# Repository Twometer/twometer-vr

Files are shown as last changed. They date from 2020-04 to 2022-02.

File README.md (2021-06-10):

<p align="center">
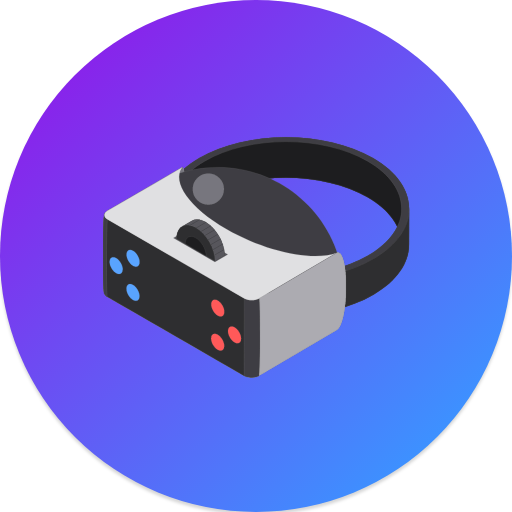
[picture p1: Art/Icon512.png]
  
  <h1 align="center">Twometer VR</h1>
</p>

An open-source alternative to commercial hand trackers such as Oculus Touch or PS Move, because Virtual Reality should not be expensive.

## Getting started

To get started with TwometerVR, check out the [homepage](https://twometer.dev/vr/).

On this page, you can find details about the project, all the technical details, as well as the download links for the hardware PCB/CAD files.

## Repository layout
- Art: All the icons, designs etc.
- Docs: MkDocs source files
- TVR.Service: The core application which manages the controllers and their inputs
- TVR.Driver: An OpenVR driver that can receive the data from the service
- TVR.Firmware: The firmware that runs on the controllers
- TVR.Setup: Setup files for building new releases

>  Looking for the code of version 1? See [here](https://github.com/Twometer/twometer-vr/tree/1.x).

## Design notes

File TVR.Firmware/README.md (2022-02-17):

# Firmware

Source code for the firmware running on the TwometerVR controllers, designed for ESP8266 chips.

## Building

You need:

-   PlatformIO (VS Code extension)
-   An ESP8266 programming device

## Recommended upload settings

-   CPU Speed: 160 MHz
-   Espressif Version: 2.2.1+100

> These are set automatically by the PlatformIO config

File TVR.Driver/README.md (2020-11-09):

# Driver
OpenVR driver implementation which connects the TVR service to games

### Directory

- `lib/`: OpenVR SDK
- `ovr/`: OpenVR driver manifests
- `src/`: Source files

### Installing
The release installation package will automatically install the driver for you. If you want to do it yourself, see the next section.

### Building from source
You will need:

- CLion or other CMake compatible IDE
- The submodules for this repo to get `.\lib\openvr`
- The MSVC compiler and Windows

Building:

- Run a CMake release build. It should automatically create the `driver_vr.dll` file required by SteamVR.
- Copy the dll file to `.\ovr\tvr\bin\win64\driver_tvr.dll`.

Installing: Run `.\ovr\Install.ps1`

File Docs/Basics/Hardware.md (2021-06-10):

# Hardware files
Here you can find the source files for building the hardware (PCBs and 3D models)

### PCBs

Each controller has three PCBs in it. They are all on EasyEDA and can be downloaded here:

- [Mainboard](https://oshwlab.com/Twometer/twometer-vr-2-0)
- [Buttons PCB](https://oshwlab.com/Twometer/twometer-vr-2-0-buttons)
- [LED PCB](https://oshwlab.com/Twometer/twometer-vr-2-0-led)

### CAD files

The case for a controller also consists of multiple 3D-printed parts. The Fusion360 files can be downloaded here:

- [Controller case](https://a360.co/38ymnGe)
- [Tracker ball](https://a360.co/38zLkB1)
- [Tracker ball adapter](https://a360.co/3poNDxz)
- [Buttons](https://a360.co/3ppm47l)

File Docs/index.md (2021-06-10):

# Welcome

TwometerVR is an open-source alternative to commercial VR hand/body tracking systems.

It's primarily intended for those who have VR headsets such as the Oculus DK2 that don't include controllers. It is a low-cost alternative to expensive commercial devices such as the PS Move or Oculus Touch system.

## Features

- 3D hand tracking controllers with 7 buttons and 9-DoF IMUs
- Works with BeatSaber, VRChat, or any other SteamVR game
- Low-cost with around $15 per controller
- Fully open-source and open-hardware

Although there is currently no implementation of full-body-tracking, the system is technically fully capable of supporting it.

## Getting started

As this is currently a hobby project of mine, there are no ready-made products or kits available for purchase.

To learn about the way the system works, check out the [system structure page](/Basics/System structure). If you're interested in the hardware, you can find all the required 3D models and PCB layouts on the [hardware page](Hardware/). The source code is available in the [GitHub repo](https://github.com/Twometer/twometer-vr).

## Pictures

todo

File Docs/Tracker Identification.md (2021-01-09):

# Tracker identification

When registering with the server, the tracker transmits its class, color and serial number. The server then generates a unique 8-bit ID for that tracker. For subsequent pose updates, only this ID is sent.

### Tracker colors

Trackers are identified by the color of their tracking ball. The following colors are reserved as they were determined to be the most distinguishable by the video camera. May change in the future as tests go on.

- `0x00`: Invalid (internal use)
- `0x01`: Red (#FF0000): Left hand
- `0x02`: Blue (#0000FF): Right hand
- `0x03`: Green (#00FF00): Left leg
- `0x04`: Magenta (#FF00FF): Right leg
- `0x05`: Cyan (#FFFF00): Hips
- `0x06`: Yellow (#FFFF00): Generic
  - Not required for 5-point body tracking and may therefore be used for any other object that should be tracked.
- `..0x7F`: Reserved for future use
- `0x80..0xFF`: May be used by extensions

### Tracker classes

- `0x00`: Invalid (internal use)
- `0x01`: Controller
- `0x02`: Body tracker
- `0x03`: Generic tracker
- `..0x7F`: Reserved for future use
- `0x80..0xFF`: May be used by extensions

### Tracker IDs

Tracker IDs are a random ID that is used to identify all trackers after `0x82 Handshake`. 

To ensure uniqueness in the current tracking setup, IDs are managed by the server. The server informs the client of its ID using the `0x83 Handshake Reply` packet.

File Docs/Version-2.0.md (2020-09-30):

# Twometer VR 2.0
Roadmap and design concept for the next generation of Twometer VR

## Roadmap

- New IMU chip for a drift-free VR experience
- More buttons on the controller to support more games
- Faster and more stable networking protocol
- Flexible, extensible, yet simple design
- Support multiple cameras and arbitrary angles
- Support 5P full-body tracking

## Naming

- Tracker: Any tracked device.
- Controller: Handheld tracked devices with button input capabilities.
- Server: The main server running in the TwometerVR service. May also be called 'service'.
- Driver: The 'driver' extension for SteamVR.

## Tracker identification

When registering with the server, the tracker transmits its class, color and model number. The server then generates a unique 8-bit ID for that tracker. For subsequent pose updates, only this ID is sent.

### Tracker colors

Trackers are identified by the color of their tracking ball. The following colors are reserved as they were determined to be the most distinguishable by the video camera. May change in the future as tests go on.

- `0x00`: Invalid (internal use)
- `0x01`: Red (#FF0000): Left hand
- `0x02`: Blue (#0000FF): Right hand
- `0x03`: Green (#00FF00): Left leg
- `0x04`: Magenta (#FF00FF): Right leg
- `0x05`: Cyan (#FFFF00): Hips
- `0x06`: Yellow (#FFFF00): Generic
  - Not required for 5-point body tracking and may therefore be used for any other object that should be tracked.
- `..0x7F`: Reserved for future use
- `0x80..0xFF`: May be used by extensions

### Tracker classes

- `0x00`: Invalid (internal use)
- `0x01`: Controller
- `0x02`: Body tracker
- `0x03`: Generic tracker
- `..0x7F`: Reserved for future use
- `0x80..0xFF`: May be used by extensions

### Tracker IDs

Tracker IDs are a random ID that is used to identify all trackers after the `0x82 Server Hello`. 

To ensure uniqueness in the current tracking setup, IDs are managed by the server. The server informs the client of its ID using the `0x83 Client Hello` packet.

## Next-gen positional tracking

The next generation positional tracking should allow for arbitrary camera angles, and multiple cameras for a larger tracking space and more accuracy.

#### Definitions

- Image space: Raw camera image space, consisting of a 2D image position and a radius
- Camera space: Ball position in 3D space, unprojected using camera parameters, but has its origin at the camera.
- World space: Ball position in 3D space, transformed so that the origin is at the center of the playspace.

#### Basic algorithm (idea)

1. Isolate the tracker ball from the image and determine position and radius
2. Using the previously determined camera parameters, unproject the tracker ball into camera space.
3. By comparing the nominal playspace cube with the rotated playspace cube registered during a calibration step, compute a matrix from camera space into world space.
4. Use said matrix to convert all camera space ball locations into world space ball locations.

## Steam VR

- Universe ID: `0x02 0x16 0x39 0xA0` = `2688095746`

## Protocol definitions

- All multi-byte integer values are little-endian
- Packets longer than 4 KB (4096 bytes) are not accepted by any endpoint
- `vec3`: 3 sequential 32-bit floating-point values in order `[x, y, z]` that encode a 3D-position
- `quat`: 4 sequential 32-bit floating-point values in order `[x, y, z, w]` that encode a quaternion
- `type[]`: Array of objects, is prefixed by a `[uint8 length]` that contains the number of objects in the array.
- `string`: NUL-terminated ASCII-encoded string

## Networking ports

- Server ⇄ Driver: `20156`
- Server ⇄ Tracker (Broadcast): `20157`
- Server ⇄ Tracker (Unicast): `20158`

## Driver Protocol

This UDP binary protocol is used for IPC between the server and the SteamVR driver.

### Base structure
```
[uint8 id][payload]
```

### 0x00 Tracker Connect

```
[uint8 trackerId][uint8 trackerClass][string modelNo]
```

### 0x01 Tracker Disconnect

If a tracker stops sending status updates for longer than 30 seconds, it is considered offline and the server will inform the driver of a lost tracker using this message.

```
[uint8 trackerId]
```

### 0x02 Tracker States

Used to tell the driver about state updates

```
[TrackerStates[] states]
```

#### Tracker state

```
[uint8 trackerId][uint16 buttons][vec3 position][quat rotation]
```

### `..0x7F` Reserved

This range is reserved for future use. Extensions may use the `0x80..0xFF` packet range.

## Tracker Protocol

Also an UDP-based binary protocol; used to tell the server about the tracker state.

### Base structure
```
[uint8 id][payload]
```

I the MSB of `id` is set (`id > 0x7F`), then the lower 7 bytes of ID are treated as the ID of a management packet. If it's not  set, the packet is interpreted as a tracker state packet and the lower 7 bytes are the tracker ID.

### `0x00-0x7F` Tracker State
```
[uint8 trackerId][uint16 buttons][quat rotation]
```

`buttons` is a bitmask for pressed buttons: LSB->MSB is button 0->15

#### Button IDs

- `0`: A
- `1`: B
- `2`: Up
- `3`: Down
- `4`: Left
- `5`: Right
- `6`: Trigger
- `7`: Menu
- `8..15`: reserved

### `0x80` Discovery (Use Broadcast Channel)

```
0x80   0x02 0x16 0x39 0xA0
pID    Identifier
```

Identifier is a static key that identifies the Twometer VR 2.0 universe. It's the same as the SteamVR universe ID.

The server must respond with `0x81 Discovery Reply`

### `0x81` Discovery Reply

```
0x81   [string serverIp]
```
 `serverIp` contains the IP or hostname of the server.

### `0x82` Server Hello

```
0x82   [uint8 trackerClass][uint8 colorId][string modelNo]
```

`modelNo` can be the ESP chip's model number.

The server must respond with `0x83 Client Hello`

### `0x83` Client Hello

```
0x83   [uint8 trackerId]
```

### `0x84` Haptic Feedback (To client only)

```
0x84   [uint16 durationMs]
```

### `..0xBF` Reserved

This packet range is reserved for (future) internal use.

Modified trackers may use the subsequent packet ID range `0xC0..0xFF` for extended functionality.

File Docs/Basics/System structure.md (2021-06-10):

# System structure

TwometerVR is a complex system with many components that need to work together in order to make it work. The components described in this document are named after the naming scheme [described here](/Meta/Naming). You may want to read this first for a clearer understanding.

## Trackers

Each tracker at least requires a glowing colored 4cm sphere for positional tracking. Trackers that also report orientation, as well as hand controllers, need more intelligent logic. They are based around an ESP8266 WiFi chip. Communication with the host computer is done using WiFi and a binary UDP protocol, which is documented [here](/Network/Driver%20Protocol). 

The WiFi chip streams the orientation of the controller along with the state of any buttons to the server. It can also receive messages, so that in the future one can add communication from the server to the client. This can be useful for features like haptic feedback.

To learn more about how the server knows which trackers are which, check out the [Tracker identification page](/Basics/Tracker identification).

## Server

The server is a program running on the host computer. It has multiple different functions:

It uses the computer's webcam (preferrably a PSMove camera for high refresh rates) to track the trackers' glowing spheres. Their 3D position is then computed and stored. The server also provides the UDP endpoint to which the trackers send their orientation and button data.

The server then merges all this data and transmits it to the SteamVR driver, which is required in order to play VR games and apps with the system.

## Driver

In order to let games know about the state of the trackers, TVR implements a SteamVR extension, called a driver. This  is the last step for the tracker data, which is received from the server and converted into a format SteamVR understands.

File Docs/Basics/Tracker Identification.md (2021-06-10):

# Tracker identification

When registering with the server, the tracker transmits its class, color and serial number. The server then generates a unique 7-bit ID for that tracker. For subsequent pose updates, only this ID is sent.

### Tracker colors

Trackers are identified by the color of their tracking ball. The following colors are reserved as they were determined to be the most distinguishable by the video camera. May change in the future as tests go on.

- `0x00`: Invalid (internal use)
- `0x01`: Red (#FF0000): Left hand
- `0x02`: Blue (#0000FF): Right hand
- `0x03`: Green (#00FF00): Left leg
- `0x04`: Magenta (#FF00FF): Right leg
- `0x05`: Cyan (#FFFF00): Hips
- `0x06`: Yellow (#FFFF00): Generic
  - Not required for 5-point body tracking and may therefore be used for any other object that should be tracked.
- `..0x7F`: Reserved for future use
- `0x80..0xFF`: May be used by extensions

### Tracker classes

- `0x00`: Invalid (internal use)
- `0x01`: Controller
- `0x02`: Body tracker
- `0x03`: Generic tracker
- `..0x7F`: Reserved for future use
- `0x80..0xFF`: May be used by extensions

### Tracker IDs

Tracker IDs are randomly generated numbers that are used to easily identify trackers after a `0x82 Handshake` packet. 

To ensure uniqueness in the current tracking setup, IDs are managed by the server. The server informs the client of its ID using the `0x83 Handshake Reply` packet.

More information about these packets packet can be found in the [protocol documentation](/Network/Tracker protocol).

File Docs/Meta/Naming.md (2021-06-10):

# Naming

Throughout the TwometerVR documentation, various naming conventions and abbreviations are used:

## Names

- Tracker: Any tracked device.
- Controller: Handheld tracked devices with button input capabilities.
- Server: The main server running in the TwometerVR service. May also be called 'service'.
- Driver: The 'driver' extension for SteamVR.
- Host computer: The PC that runs the server, SteamVR etc.

## Abbreviations

- TVR: TwometerVR 
- OVR: OpenVR / SteamVR

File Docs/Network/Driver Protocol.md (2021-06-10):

# Driver Protocol

This UDP binary protocol is used for IPC between the server and the SteamVR driver.

### Base structure

```
[uint8 id][payload]
```

### `0x00` Tracker Connect

Sent by the server to inform the driver of a new tracker

```
[uint8 trackerId][uint8 trackerClass][uint8 trackerColor][string serialNo]
```

### `0x01` Tracker Disconnect

If a tracker stops sending status updates for longer than 30 seconds, it is considered offline and the server will inform the driver of a lost tracker using this message.

```
[uint8 trackerId]
```

### `0x02` Tracker States

Used to tell the driver about state updates

```
[TrackerStates[] states]
```

#### Tracker state

```
[uint8 trackerId][uint16 buttons][vec3 position][vec4 rotation][bool inRange]
```

### `0x03` Request Info

Sent by the driver on starting up to request tracker information.

Has no content.

### `..0x7F` Reserved

This range is reserved for future use. Extensions may use the `0x80..0xFF` packet range.

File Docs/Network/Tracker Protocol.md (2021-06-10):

# Tracker Protocol

This UDP binary protocol is used for communication between the server and the trackers.

### Base structure

```
[uint8 id][payload]
```

If the MSB of `id` is set (`id & 0x80 != 0`), then the lower 7 bytes of ID are treated as the ID of a management packet. If it's not  set, the packet is interpreted as a tracker state packet and the lower 7 bytes are the tracker ID.

### `0x00-0x7F` Tracker State

```
[uint8 trackerId][uint16 buttons][vec4 rotation]
```

`buttons` is a bitmask for pressed buttons: LSB->MSB is button 0->15

The button IDs are defined in the definitions file.

### `0x80` Discovery (Use Broadcast Channel)

```
0x80   0x02 0x16 0x39 0xA0
pID    Identifier
```

Identifier is a static key that identifies the Twometer VR 2.0 universe. It's the same as the SteamVR universe ID.

The server must respond with `0x81 Discovery Reply`

### `0x81` Discovery Reply

```
0x81   [string serverIp]
```

 `serverIp` contains the IP or hostname of the server.

### `0x82` Handshake

```
0x82   [uint8 trackerClass][uint8 colorId][string serialNo]
```

`serialNo` is formatted as `[manufacturerId][chipId]`, so for TwometerVR controllers with an ESP Chip `TVR[ESP.chipId]`.

The server must respond with `0x83 Handshake Reply`

### `0x83` Handshake Reply

```
0x83   [uint8 trackerId]
```

### `..0xBF` Reserved

This packet range is reserved for (future) internal use.

Modified trackers may use the subsequent packet ID range `0xC0..0xFF` for extended functionality.

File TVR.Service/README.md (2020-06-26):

# Service
The Service is the core of TwometerVR. It is the bridge between all the connected devices and SteamVR, provides a user interface and handles visual controller tracking using the webcam.

## Project structure
- Core libraries
  - `TVR.Service.Core`: Contains all the tracking and processing logic
  - `TVR.Service.Network`: Implements the servers, discovery and protocols
  - `TVR.Service.Common`: Common API which makes it easier to build a frontend
- Frontends
  - `TVR.Service.CLI`: Console interface for debugging.
  - `TVR.Service.UI`: User-friendly modern GUI frontend. Includes setup assistant.

## Getting Started
For details on how to configure and run the service, check out the [Wiki](https://github.com/Twometer/twometer-vr/wiki)

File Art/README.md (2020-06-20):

# Artwork
This folder contains icons and other artwork for TwometerVR

## Icon license
> Icons made by [Freepik](https://www.flaticon.com/de/autoren/freepik) from [Flaticon](https://www.flaticon.com/de/).
I used and modified their VR headset icon for my logo.

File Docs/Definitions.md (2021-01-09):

## Steam VR

- Universe ID: `0x02 0x16 0x39 0xA0` = `2688095746`

## Networking ports

- Server ⇄ Driver: `20156`
- Server ⇄ Tracker (Broadcast): `20157`
- Server ⇄ Tracker (Unicast): `20158`

## Protocol definitions

- All multi-byte integer values are little-endian
- Packets longer than 4 KB (4096 bytes) are not accepted by any endpoint
- `vec3`: 3 sequential 32-bit floating-point values in order `[x, y, z]` that encode a 3D-position
- `vec4`: 4 sequential 32-bit floating-point values in order `[x, y, z, w]` that encode a quaternion
- `type[]`: Array of objects, is prefixed by a `[uint8 length]` that contains the number of objects in the array.
- `string`: NUL-terminated ASCII-encoded string

## Button IDs

- `0`: A
- `1`: B
- `2`: Up
- `3`: Left
- `4`: Right
- `5`: Down
- `6`: Menu
- `7`: Trigger
- `8..15`: reserved

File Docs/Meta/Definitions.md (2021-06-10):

# Definitions

There are many constants used throughout the TVR project. Below, you can find an overview of them.

## Steam VR

- Universe ID: `0x02 0x16 0x39 0xA0` = `2688095746`

## Networking ports

- Server ⇄ Driver: `20156`
- Server ⇄ Tracker (Broadcast): `20157`
- Server ⇄ Tracker (Unicast): `20158`

## Protocol definitions

- All multi-byte integer values are little-endian
- Packets longer than 4 KB (4096 bytes) are not accepted by any endpoint
- `vec3`: 3 sequential 32-bit floating-point values in order `[x, y, z]` that encode a 3D vector
- `vec4`: 4 sequential 32-bit floating-point values in order `[x, y, z, w]` that encode a quaternion
- `type[]`: Array of objects, is prefixed by a `[uint8 length]` that specifies the number of objects in the array.
- `string`: Null-terminated, ASCII-encoded string

## Button IDs

- `0`: A
- `1`: B
- `2`: Up
- `3`: Left
- `4`: Right
- `5`: Down
- `6`: Menu
- `7`: Trigger
- `8..15`: reserved

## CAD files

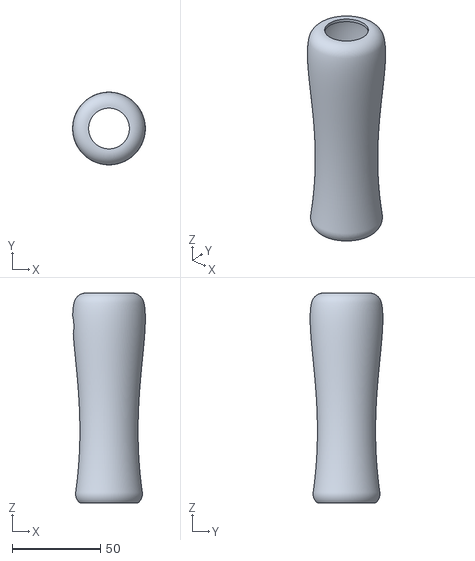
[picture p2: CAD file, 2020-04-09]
hw/controller_handle.stl
41.1 x 41.1 x 118.7

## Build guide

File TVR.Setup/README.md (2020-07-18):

# Setup
This folder contains all files necessary to build a new release

## Build system
- The setup application is a C# application that lives in the `Installer` directory
- The runtime zip is generated with the `New-Release.ps1` PowerShell script

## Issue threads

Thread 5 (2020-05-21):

Yaw Drift

Twometer, 2020-05-21:
Despite many fixes, the software-based 9-DOF sensor fusion still doesn't work and we have to use the 6-axis fusion provided by the DMP. Therefore, we have yaw drift which has to be fixed.

Closed 2020-08-07.

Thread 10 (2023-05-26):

Hompage for twometer vr

pppardo, 2023-05-26:
Can´t access homepage, 404 Not Found
Where can i find details about the project, all the technical details, as well as the download links for the hardware PCB/CAD files ?

Twometer, 2023-05-26:
The server that's linked in GitHub recently died, and I've lost the homepage. However, most of the documentation should still be in the "Docs" folder in the repository.

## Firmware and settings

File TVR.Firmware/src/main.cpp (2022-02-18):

#include <Arduino.h>
#include <EEPROM.h>
#include <ESP8266WiFi.h>
#include <stdint.h>

#include "IO/ButtonInput.h"
#include "IO/PoseInput.h"
#include "Model/TrackerClass.h"
#include "Model/TrackerColor.h"
#include "Net/Discovery.h"
#include "Net/NetDefs.h"
#include "Net/UdpClient.h"
#include "Net/WiFiCredentials.h"
#include "Utils/Constants.h"
#include "Utils/SerialNo.h"

const TrackerClass trackerClass = TrackerClass::Controller;
const TrackerColor trackerColor = TrackerColor::Blue;

ButtonInput buttonInput;
PoseInput poseInput;
UdpClient client;

uint8_t trackerId;

void setupHardware() {
    Logger::info("Setting up hardware...");
    buttonInput.begin();
    poseInput.begin();
    EEPROM.begin(1024);
}

void setupWifi() {
    Logger::info("Connecting to WiFi " WIFI_SSID "...");
    WiFi.persistent(true);
    WiFi.mode(WIFI_STA);
    WiFi.begin(WIFI_SSID, WIFI_PASS);

    while (WiFi.status() != WL_CONNECTED) {
        delay(100);
    }

    Logger::info("Connected.");
}

void dumpCalibrationData(const CalibrationData &calibData) {
    Serial.printf("Accel: %d %d %d\n", calibData.accelBias[0], calibData.accelBias[1], calibData.accelBias[2]);
    Serial.printf(" Gyro: %d %d %d\n", calibData.gyroBias[0], calibData.gyroBias[1], calibData.gyroBias[2]);
    Serial.printf("  Mag: %d %d %d\n", calibData.magBias[0], calibData.magBias[1], calibData.magBias[2]);
}

void loadCalibrationData() {
    Logger::info("Loading calibration data");
    if (EEPROM.read(0) == 0x42) {
        CalibrationData data{};
        EEPROM.get(4, data);
        dumpCalibrationData(data);
        poseInput.setCalibrationData(data);
        Logger::info("Load successful");
    } else {
        Logger::info("EEPROM has no data");
    }
}

unsigned long long lastSave = 0;
void saveCalibrationData() {
    if (millis() - lastSave > 60000) {
        auto data = poseInput.getCalibrationData();
        EEPROM.write(0, 0x42);
        EEPROM.put(4, data);
        EEPROM.commit();
        dumpCalibrationData(data);
        lastSave = millis();
    }
}

void runServerDiscovery() {
    Logger::info("Attempting to discover server...");
    Discovery discovery;
    IPAddress serverIp = discovery.discover();
    client.begin(serverIp, UNICAST_PORT);
    Serial.print("Server IP: ");
    Serial.println(serverIp);
    Logger::info("Successfully found server.");
}

void runServerRegistration() {
    Logger::info("Registering with the server...");
    Packets::sendHello(client, trackerClass, trackerColor, SerialNo::get());
    Packets::receiveHello(client, trackerId);
    Serial.printf("Tracker id: %d\n", trackerId);
    Logger::info("Successfully registered with the server.");
}

void setup() {
    Serial.begin(115200);
    Serial.println("");
    Serial.println(VERSION_STRING);

    setupHardware();
    setupWifi();
    loadCalibrationData();
    runServerDiscovery();
    runServerRegistration();

    Logger::info("Initialization sequence completed.");
}

void runTick() {
    buttonInput.update();
    poseInput.update();

    if (poseInput.available()) {
        Packets::sendState(client, trackerId, buttonInput.getStates(), poseInput.getPose());
        poseInput.clearAvailable();
        saveCalibrationData();
    }
}

void loop() {
    uint64_t tickStart = micros64();
    runTick();
    uint64_t tickDuration = micros64() - tickStart;
    if (tickDuration < TICK_PERIOD_US) {
        uint64_t remainingTime = TICK_PERIOD_US - tickDuration;
        delayMicroseconds(remainingTime);
    }
}

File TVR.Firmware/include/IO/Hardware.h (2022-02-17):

#ifndef TVR_HARDWARE
#define TVR_HARDWARE

// IMU pins
#define PIN_SDA 4
#define PIN_SCL 5

// Shift register pins
#define PIN_SHLD 16
#define PIN_CE   12
#define PIN_CLK  14
#define PIN_DATA 13

#endif

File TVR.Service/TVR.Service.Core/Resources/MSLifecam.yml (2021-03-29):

# Config file for the Microsoft LifeCam HD-3000

VideoSourceType: DirectShow
VideoSourceIndex: 0
FrameWidth: 1280
FrameHeight: 720
Framerate: 30
TransformConfig:
    PFocalLength: 1350
    PixelsPerMeter: 1118.5
ExposureConfig:
    Start: -5
    Limit: -25
    Step: -1
    WarmupFrames: 12
    CooldownFrames: 3
    StableFrames: 2
    MaximumChange: 2.0
    Threshold: 20
Distortion: []
UseAdaptiveBrightness: True

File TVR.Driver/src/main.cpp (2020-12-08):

#include "Driver/ServerDriver.h"
#include "Driver/WatchdogDriver.h"
#include "Utils/OpenVrExports.h"

ServerDriver serverDriver;
WatchdogDriver watchdogDriver;

HMD_DLL_EXPORT void *HmdDriverFactory(const char *pInterfaceName, int *pReturnCode) {
    if (strcmp(vr::IServerTrackedDeviceProvider_Version, pInterfaceName) == 0) {
        return &serverDriver;
    }
    if (strcmp(vr::IVRWatchdogProvider_Version, pInterfaceName) == 0) {
        return &watchdogDriver;
    }

    if (pReturnCode)
        *pReturnCode = vr::VRInitError_Init_InterfaceNotFound;
    return nullptr;
}

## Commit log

2020-04-05 Switch to EmguCV
2020-04-05 Camera and math basics
2020-04-06 Fix calibration bug and add 3d preview
2020-04-06 Add localhost server for sending updates to the Driver
2020-04-06 Add stl models
    [controller_handle.stl, sphere.stl, sphere_adapter.stl]
2020-04-06 Add project for the driver
2020-04-06 Add data model to driver
2020-04-06 Network client in the driver
2020-04-07 Improve accuracy of camera calibration
2020-04-07 Switch from polling to async callbacks
2020-04-08 Driver basics
2020-04-08 Change button IDs
2020-04-08 Fully implement a basic SteamVR driver
2020-04-08 Add driver configuration resources
2020-04-08 Update docs and add PCB link
    [controller_handle.stl, sphere.stl, sphere_adapter.stl]
2020-04-09 Transmit button presses
2020-04-09 Actually retain button presses in the server
2020-04-09 Improve 3D models
    [controller_handle.stl, controller_lid.stl]
2020-04-09 Added holes to the lid for LEDs
    [controller_lid.stl]
2020-04-09 Fixed the lid again
    [controller_lid.stl]
2020-04-09 Widen LED holes to make LEDs fit
    [controller_lid.stl]
2020-04-10 More testing in the SteamVR driver
2020-04-11 Use two separate halves for the handle to simplify assembly
    [controller_handle_1.stl, controller_handle_2.stl]
2020-04-13 Driver: convert TVR pose data to SteamVR pose data
2020-04-13 Connect to the driver properly
2020-04-13 Fix bug in the controller that prevented button clicks
    [Button.h]
2020-04-13 Correctly process button presses
    [Button.h]
2020-04-13 Make z-calibration work so that the sabers are next to you
2020-04-13 Add controller button bindings
2020-04-13 Update protocol for simpler button press transmission
2020-04-13 Fix bug that prevented buttons from being detected
2020-04-13 Visualize button presses in UI
2020-04-13 Update installation guide with button mapping instructions
2020-04-14 Improve calibration button handling
2020-04-14 Make EmguCV use full camera resolution for more tracking area
2020-04-15 Code restructuring for more filter possibilities
2020-04-17 Fix multiple memory leaks
    [TVR.Firmware.ino]
2020-04-20 Remove old v1 firmware from the repo
    [controller_handle_1.stl, controller_handle_2.stl, controller_lid.stl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]
2020-04-21 Switch to new library for firmware
2020-04-21 Improve driver docs
2020-04-21 Update controller position even if temporarily not detected by camera
2020-04-21 Sensor calibration
2020-04-24 Update pages in the wizard for new flow
2020-04-25 Prevent infinite calibration
2020-04-25 Fix bugs that prevented receive from continuing
    [TVR.Firmware.ino]
2020-04-25 Fix bugs in the protocol for UDP
    [TVR.Firmware.ino]
2020-04-26 Reduce update rate to 90 Hz to reduce load on the ESPs
2020-04-29 Improve some design files
    [button.stl, button_spacer.stl, sphere.stl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]
2020-04-30 Design changes to the lid
    [controller_lid.stl]
2020-05-01 Improve drift correction algorithm and connect it with main code
    [TVR.Firmware.ino]
2020-05-02 Redesign the handle
    [controller_handle_1.stl, controller_handle_2.stl]
2020-05-02 Revert "Redesign the handle"
    This reverts commit 56ad4858869ec1b0d3c86888840f95aeb332e804.
    [controller_handle_1.stl, controller_handle_2.stl]
2020-05-03 Make it possible to turn off drift correction
    [TVR.Firmware.ino]
2020-05-03 Notify server when calibration finished
2020-05-05 New 9-axis sensor fusion
2020-05-05 Store calibration data in EEPROM
2020-05-05 Make factory reset for recalibration possible
    [Constants.h, TVR.Firmware.ino]
2020-05-05 Config fix: New firmware does not require pitch invert
2020-05-06 Allow settings for sampling sensor higher than the packet rate
2020-05-11 Modify handles to be easier to print
    [controller_handle_1.stl, controller_handle_2.stl]
2020-05-11 Add a 3D-printing stabilizer
    [controller_handle_3dpstabilizer.stl]
2020-05-12 3D print attempt No. 999: Make stabilizer bigger to keep it from falling over
    [controller_handle_3dpstabilizer.stl]
2020-05-12 Remove stabilizer
    [controller_handle_3dpstabilizer.stl]
2020-05-13 Make driver reconnect automatically
2020-05-14 New hardware does not longer require inverted yaw
2020-05-14 Default invert the pitch
2020-05-15 Fix a lot of bugs
    [DmpPoseSource.h, SwPoseSource.h, TVR.Firmware.ino]
2020-05-17 Fix some more bugs
    [DmpPoseSource.h, SwPoseSource.h]
2020-05-20 Fixed more issues with the software sensor fusion, still not 100%
    [SwPoseSource.h, TVR.Firmware.ino]
2020-05-20 Switch back to DMP mode
2020-05-21 Switch to direct quaternion transmission
2020-05-21 Fix coordinate system and issues
    [DmpPoseSource.h, TVR.Firmware.ino]
2020-05-21 Quaternion math framework for pose reset
2020-05-22 Improve camera tracker efficiency
2020-05-22 Adaptive range filtering
2020-05-22 Adaptive calibration end trigger
2020-05-22 Correctly display the button binding point
2020-05-22 Remove pitch invert from config
2020-06-21 Common namespace: Framework fro frontends
2020-06-21 Fix project files and add calibration
2020-06-21 Fix some issues with the service: Now successfully loads the config and camera
2020-06-23 Automatic detection of camera calibration parameters
2020-06-23 Clean up some code and add basics for camera calibration
2020-06-24 Calibration now working with the camera setup
2020-06-24 Fix bugs with tracker, calibration now working correctly
2020-07-17 Design camera smoothing algorithm
2020-08-07 Finally fix the drift and switch to Madgwick fusion, closes #5
    [TVR.Firmware.ino]
2020-08-07 Create an assistant UI that guides the user through calibration
    Magnetic calibration, which now has to be done on first setup, is somewhat more complicated than the old DMP-method which just required the user to lay it on a flat surface. Therefore, the app now ha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
2020-08-17 Switch to custom fork of library
2020-11-05 Some cleanup in preparation for the next verison
    [button.stl, button_spacer.stl, controller_handle_1.stl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]
2020-11-08 Begin new driver
2020-11-08 Basic OpenVR driver
2020-11-09 Basic network model and UDP client for the driver
2020-11-09 Driver README
2020-11-11 Test project: PSEye and DShow cameras working with OpenCV
2020-11-11 Tracking tests with the new camera
2020-12-08 Separate server and tracker driver
2020-12-09 Driver: Packet parser and model
2020-12-09 Driver: Code cleanup
2020-12-20 Driver: Device management
2020-12-20 Driver: Buttons
2020-12-20 Driver: Update manifest
2020-12-20 Service: Implement camera transform
2020-12-20 Service: Fix binary compatibility and fix driver client receiving its own messages
2020-12-22 Fix naming of model number vs serial number
    [Constants.h]
2020-12-22 Expand driver protocol with Tracker.InRange property
2020-12-29 Firmware: Fix various bugs
    [TVR.Firmware.ino]
2020-12-29 Service: Fix update timer not firing
2021-01-03 Firmware: Fix bug with button input
    [ButtonInput.h, TVR.Firmware.ino]
2021-01-04 Service: Add calibration tool
2021-01-04 Driver: Add standalone debug executable
2021-01-04 Driver: Fix bugs with network stack
2021-01-04 Service: Fix driver client binding to IP
2021-01-04 Driver: Fix update function not called
2021-01-04 Driver: Fix quaternion coordinate system
2021-01-04 Driver: Make debug mode driver not crash
2021-01-04 Service: Fix issue with multi-range color filter
    [PSEye.yml]
2021-01-05 Driver: Fix tracker driver reusing
2021-01-09 Driver: Redesign some of the driver networking for more stability
    [Constants.h]
2021-03-29 Fix some issues and improve drift
    [Constants.h, TVR.Firmware.ino]
2022-02-17 Firmware: Switch to PlatformIO
2022-02-18 Firmware: Read calibration data from DMP
2022-02-18 Firmware: Save and load calibration data
2022-10-26 Replace CLEye with open-source PSEye driver
